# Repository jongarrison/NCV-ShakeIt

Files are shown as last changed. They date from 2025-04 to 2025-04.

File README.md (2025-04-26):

# NCV-ShakeIt
## (Non Contact Voltage Detecting Time Delayed Relay With Audio Feedback)

<div style="width: 100%; text-align: center;">
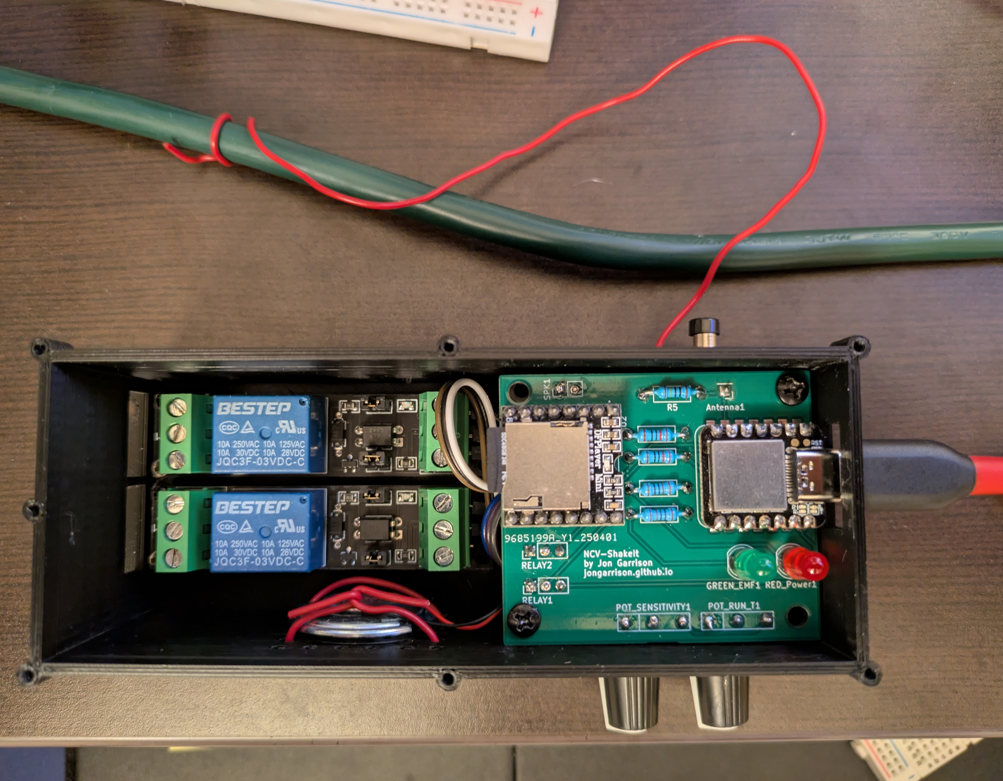
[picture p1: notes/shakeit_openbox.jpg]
    
</div>

This device is designed to turn on two relays (currently for a single two phase motor) after detecting that another AC device has shut off. The running of the other AC device is detected using a Non-contact Voltage (NCV) detector. When the device is about to trigger the relays, it plays some audio feedback (mp3 files) to let people know the motor is about to run.

Basic functions:
* Device has an antenna for detecting 60hz AC power in a nearby wire. If AC is detected for longer than a minimum threshold the system is ready to trigger when the AC next shuts off. The sensitivity of the AC detection is controlled by a potentiometer knob.
* The device waits for some interval while the main motor system spools down. During this spool down period audio is played to indicate what is happening.
* After the spool down period, two relays are turned on for an interval set by another potentiometer knob. 

# Technical Details

### Non-contact Voltage Detector circuit and algorithm
* Based on this very cool project: https://www.instructables.com/Contactless-AC-Detector/

### PCB Design
* Kicad files are provided in ./PCB_NCV-ShakeIt

<div style="width: 100%; text-align: center;">
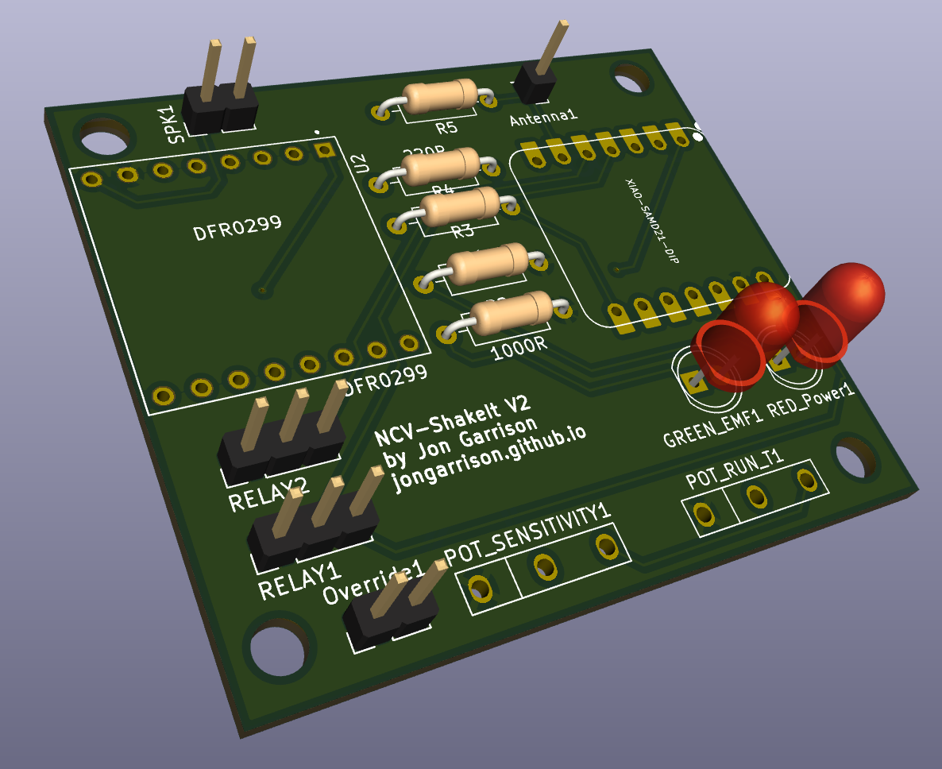
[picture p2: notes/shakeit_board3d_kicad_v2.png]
    
</div>

### Enclosure Design
* Done in Rhino3D Grasshopper. Files found in ./ShakeIt_enclosure

<div style="width: 100%; text-align: center;">
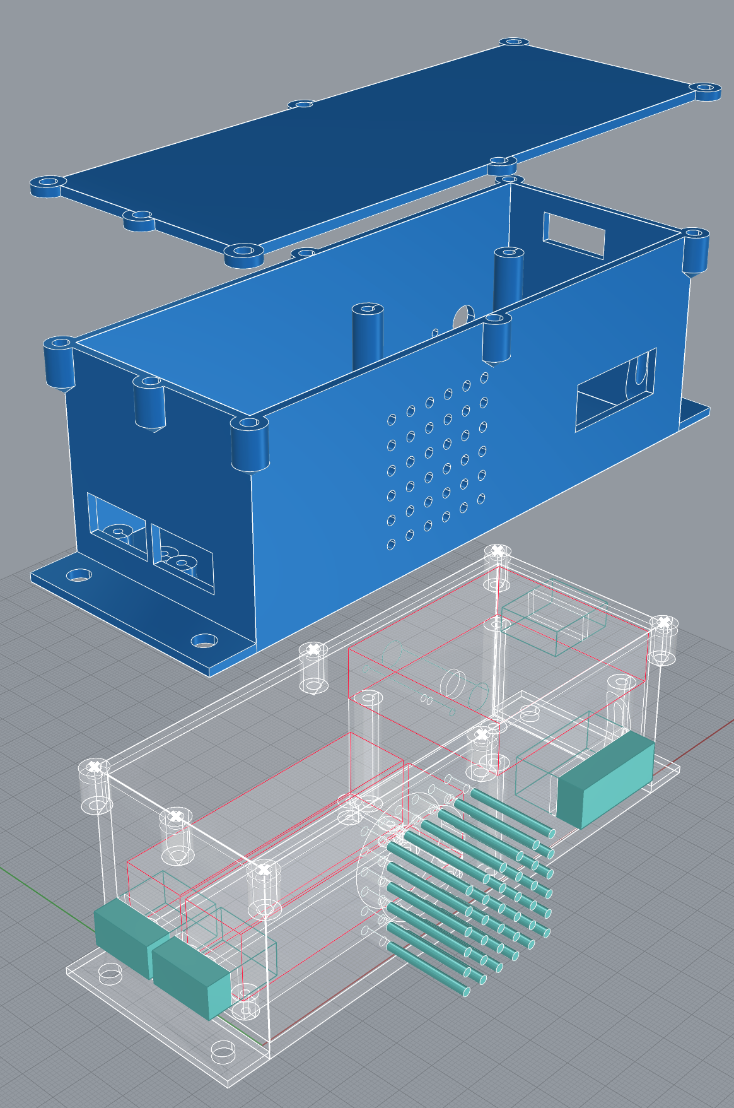
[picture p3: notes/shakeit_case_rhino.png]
    
</div>

### Microcontroller
* [Seeed Xiao SAMD21 board](https://wiki.seeedstudio.com/Seeeduino-XIAO/) - [Pinout](https://wiki.seeedstudio.com/Seeeduino-XIAO/#hardware-overview)

### MP3 Playback - DFPlayer
* [Usage Tips](https://reprage.com/posts/2018-05-08-dfplayer-mini-cheat-sheet/)

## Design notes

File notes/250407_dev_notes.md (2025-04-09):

4/7/25 Received the boards and assembled them. They work, BUT...

- Both speaker pins on the DF Mini Player should have been exposed via the header outputs
- An override switch should have been included
- Some sort of access to the SAMD21 reset is needed. Perhaps some terminals to pads for a switch? Perhaps have jumper wires from the topside reset contacts to the terminals
- Expose all of the pins of the SAMD21 with through hole connectors alongside the existing pin pads? This would allow easier repurposing of the boards.
- Replace the 1M resistor with a 1M trim pot?

Notes from initializing the 

        bool initDfPlayerWithRetry(int volume) {
            //Serial1.begin(9600); // Must be done in setup()

            while (!initDfPlayer(volume)) {
                Serial.println(F("Retrying to initialize DFPlayer ..."));
                delay(5000);
            }

            if (myDFPlayer.available()) {
                printDfPlayerDetail(myDFPlayer.readType(), myDFPlayer.read());
            }

            return true;

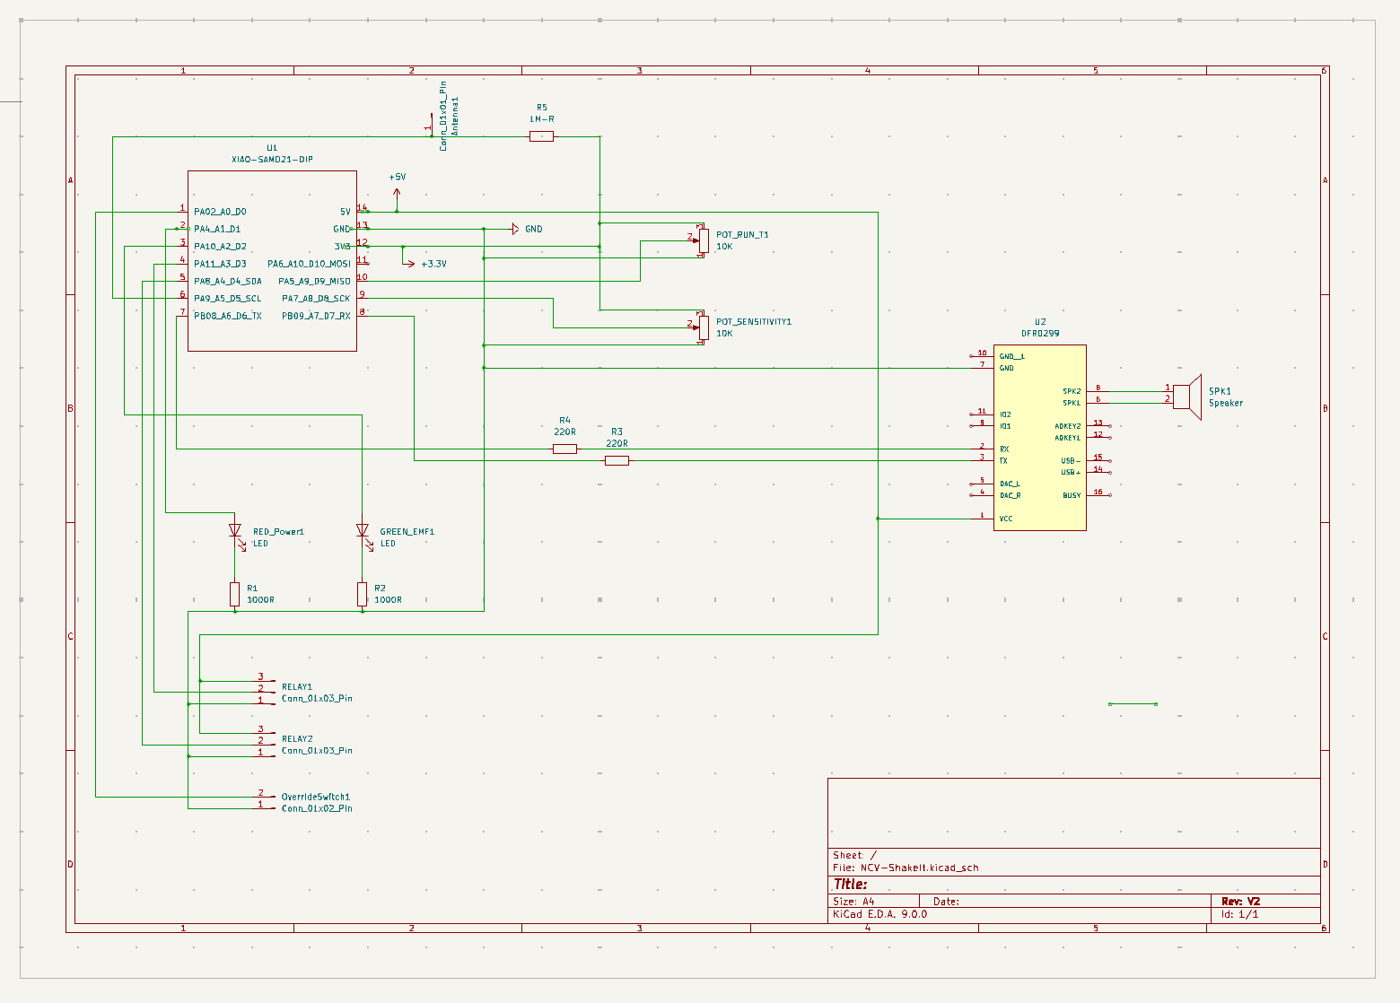
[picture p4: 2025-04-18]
notes/shakeit_schematic.png

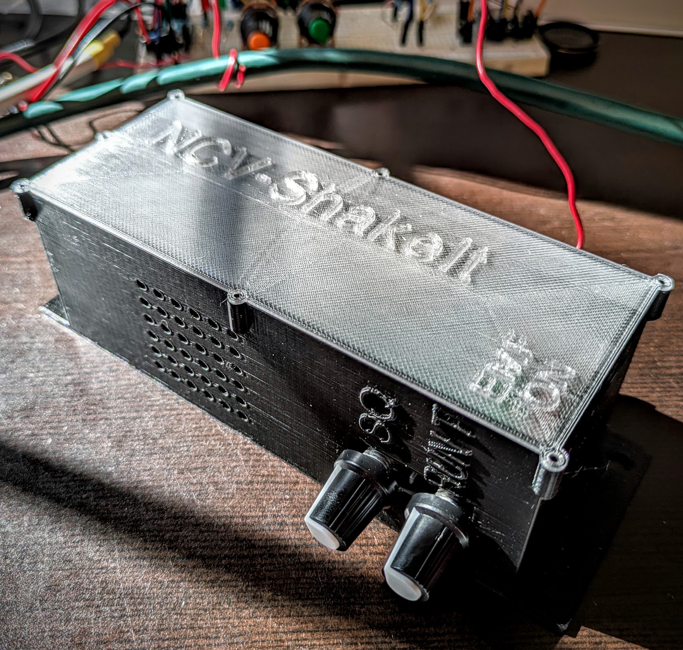
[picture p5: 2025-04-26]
notes/shakeit_complete.jpg

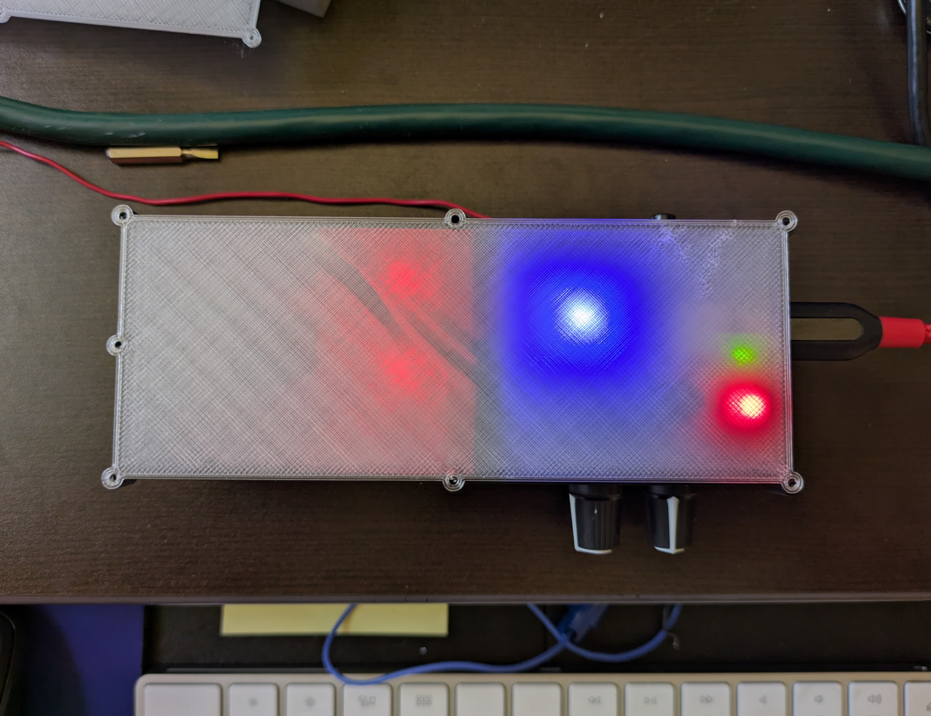
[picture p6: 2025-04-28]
notes/shakeit_lights.jpg

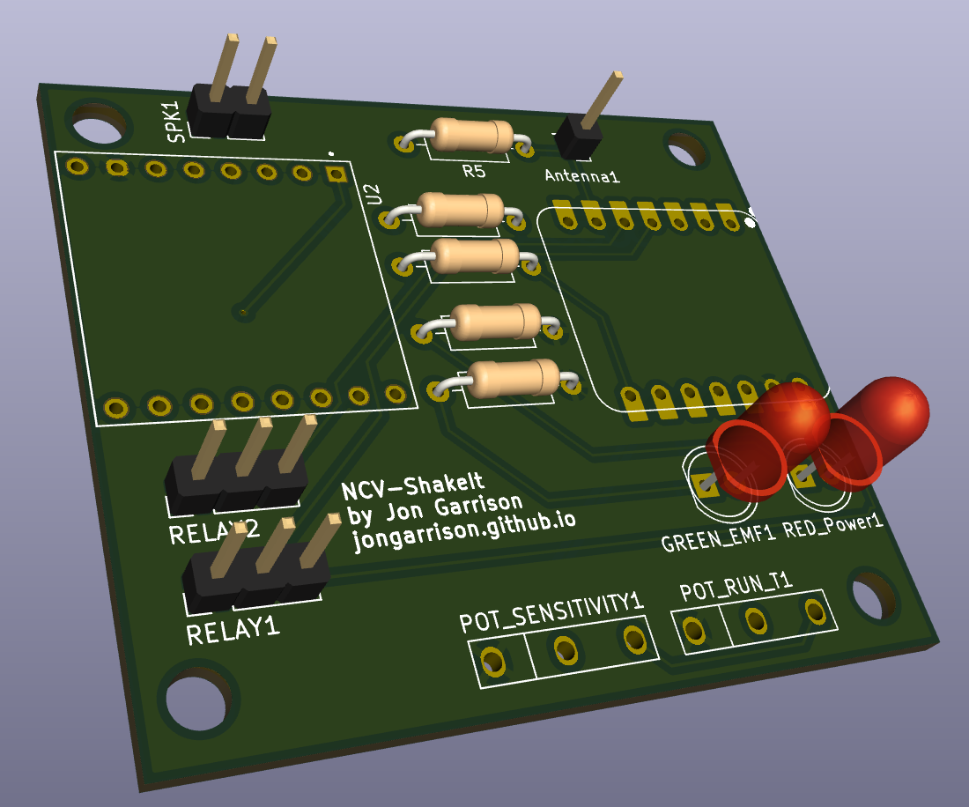
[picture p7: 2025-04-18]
notes/shakeit_board3d_kicad_v1.png

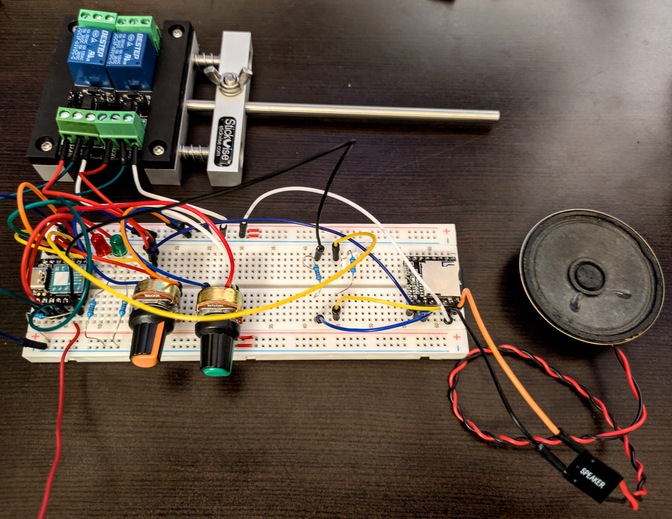
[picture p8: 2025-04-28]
notes/shakeit_prototype.jpg

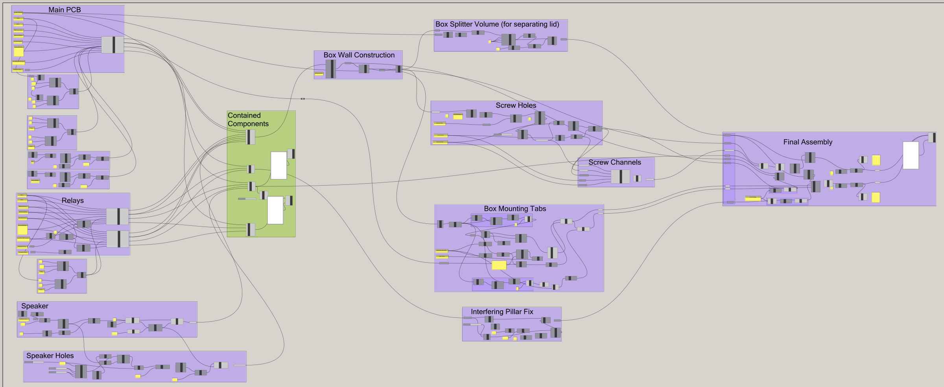
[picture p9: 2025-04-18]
notes/shakeit_grasshopper.png

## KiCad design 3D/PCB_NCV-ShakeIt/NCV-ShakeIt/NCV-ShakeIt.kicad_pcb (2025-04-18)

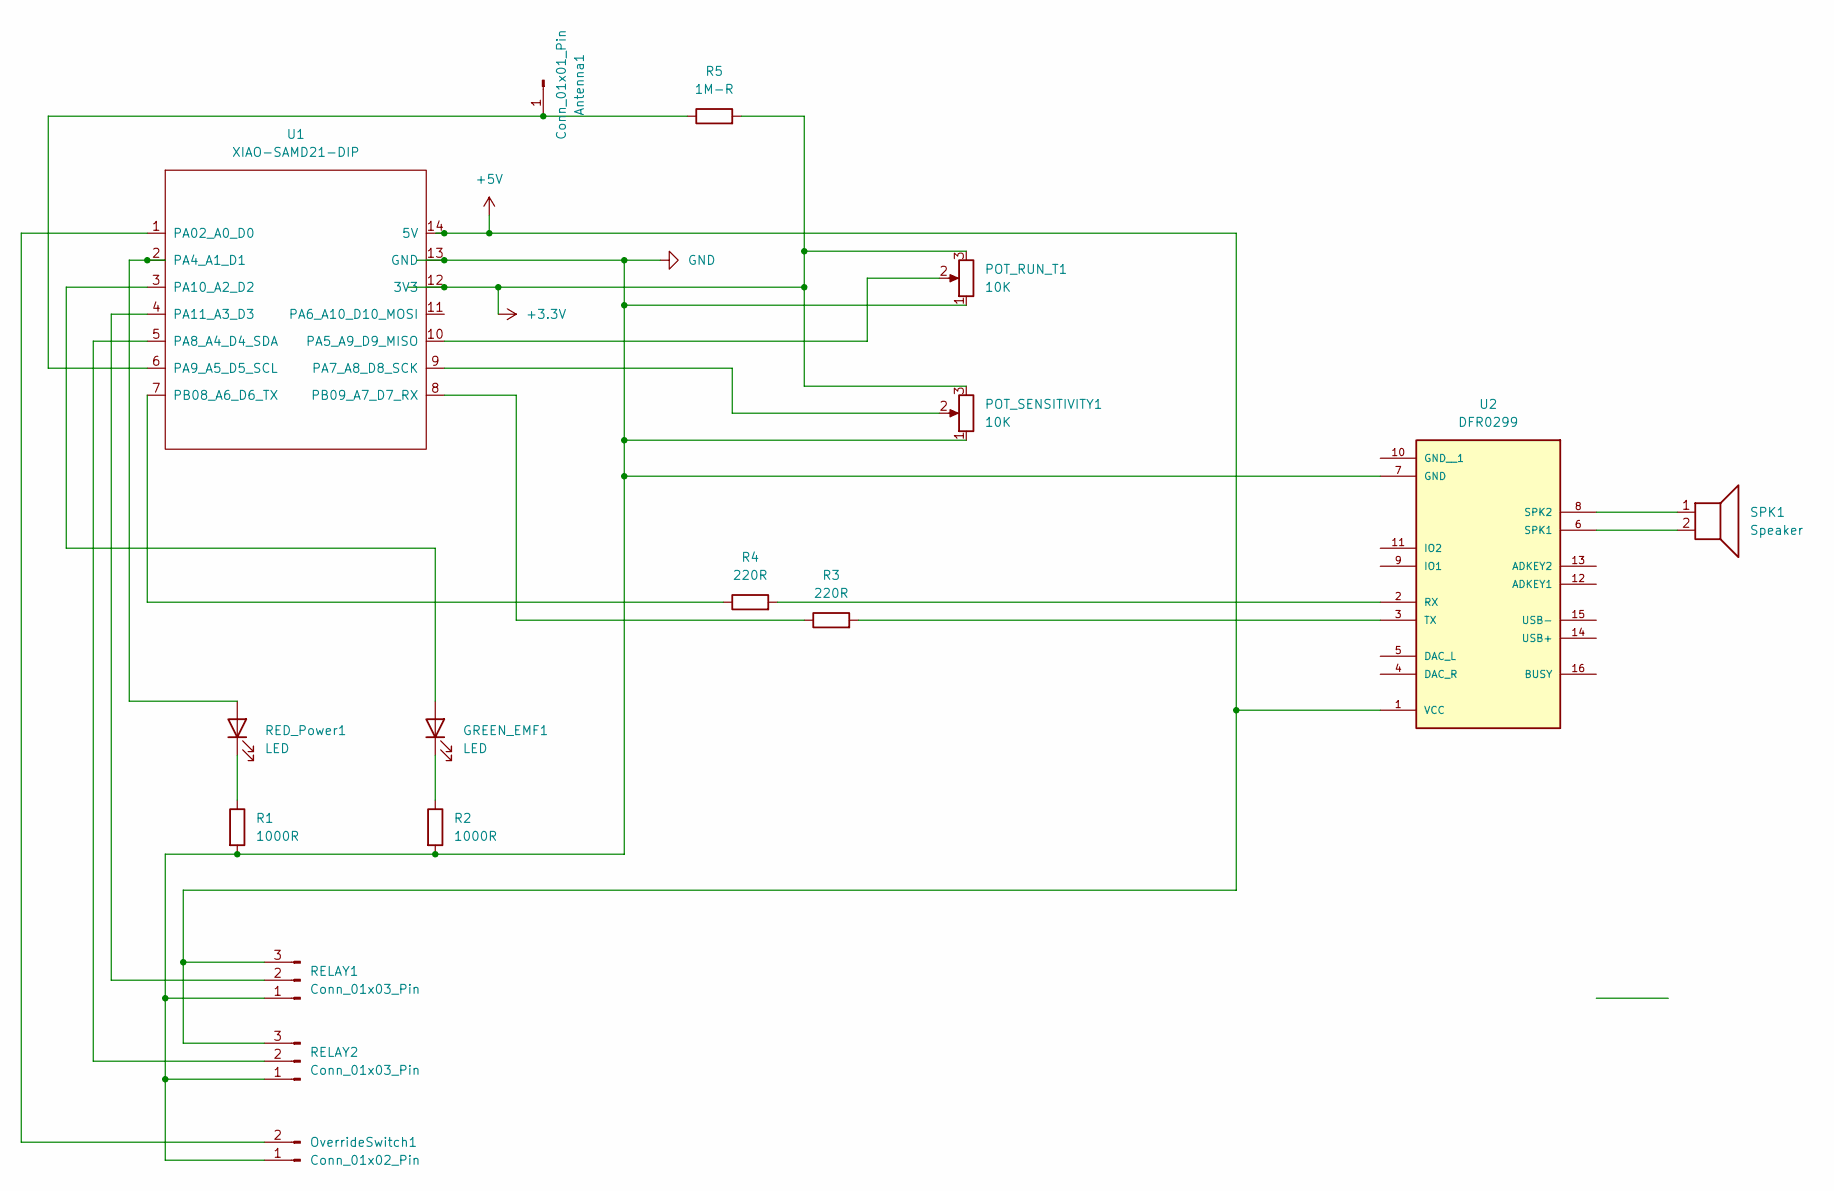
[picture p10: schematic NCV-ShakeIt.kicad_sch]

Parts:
Antenna1: Conn_01x01_Pin; PinHeader_1x01_P2.54mm_Vertical
GREEN_EMF1: LED; LED_D5.0mm
OverrideSwitch1: Conn_01x02_Pin; PinHeader_1x02_P2.54mm_Vertical
POT_RUN_T1: 10K; JG-3Pin-Pot-11mmOuterPins
POT_SENSITIVITY1: 10K; JG-3Pin-Pot-11mmOuterPins
R1, R2: 1000R; R_Axial_DIN0207_L6.3mm_D2.5mm_P10.16mm_Horizontal
R3, R4: 220R; R_Axial_DIN0207_L6.3mm_D2.5mm_P10.16mm_Horizontal
R5: 1M-R; R_Axial_DIN0207_L6.3mm_D2.5mm_P10.16mm_Horizontal
RED_Power1: LED; LED_D5.0mm
RELAY1, RELAY2: Conn_01x03_Pin; PinHeader_1x03_P2.54mm_Vertical
SPK1: Speaker; PinHeader_1x02_P2.54mm_Vertical
U1: XIAO-SAMD21-DIP
U2: DFR0299; MODULE_DFR0299

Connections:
+3.3V: POT_RUN_T1.3, POT_SENSITIVITY1.3, R5.2, U1.12 (3V3)
+5V: RELAY1.3, RELAY2.3, U1.14 (5V), U2.1 (VCC)
GND: OverrideSwitch1.1, POT_RUN_T1.1, POT_SENSITIVITY1.1, R1.2, R2.2, RELAY1.1, RELAY2.1, U1.13 (GND), U2.7 (GND); also elsewhere on the board
unnamed: Antenna1.1, R5.1, U1.6 (PA9_A5_D5_SCL)
unnamed: GREEN_EMF1.2 (A), U1.3 (PA10_A2_D2)
unnamed: GREEN_EMF1.1 (K), R2.1
unnamed 6: OverrideSwitch1.2, U1.1 (PA02_A0_D0); also elsewhere on the board
unnamed: RED_Power1.2 (A), U1.2 (PA4_A1_D1)
unnamed: R1.1, RED_Power1.1 (K)
unnamed: RELAY1.2, U1.4 (PA11_A3_D3)
unnamed: RELAY2.2, U1.5 (PA8_A4_D4_SDA)
unnamed: POT_RUN_T1.2, U1.10 (PA5_A9_D9_MISO)
unnamed: POT_SENSITIVITY1.2, U1.9 (PA7_A8_D8_SCK)
unnamed: R4.1, U1.7 (PB08_A6_D6_TX)
unnamed: R3.1, U1.8 (PB09_A7_D7_RX)
unnamed: R4.2, U2.2 (RX)
unnamed: SPK1.2, U2.6 (SPK1)
unnamed: SPK1.1, U2.8 (SPK2)
unnamed: R3.2, U2.3 (TX)

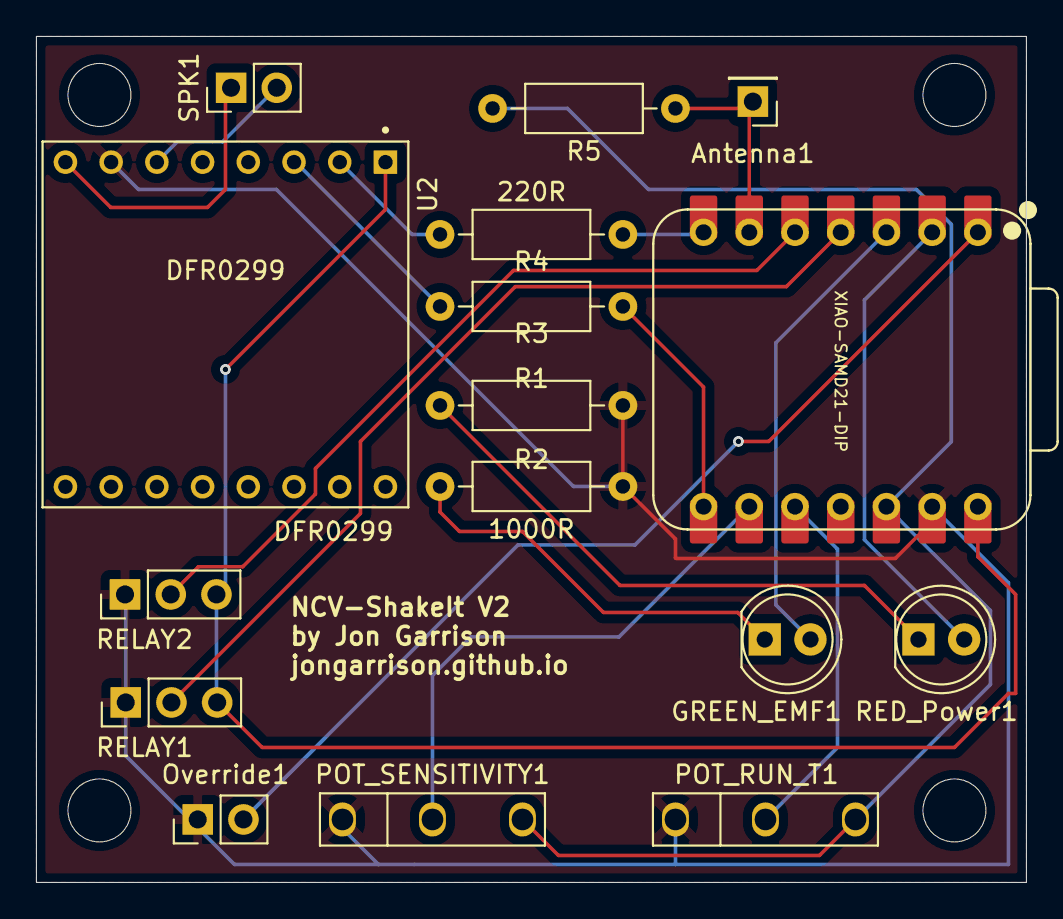
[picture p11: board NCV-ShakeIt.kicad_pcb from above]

Board: 2 copper layers, 55.0 x 47.0 mm, 16 parts (0 on the bottom side), 19 nets.

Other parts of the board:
Override1: Conn_01x02_Pin; PinHeader_1x02_P2.54mm_Vertical

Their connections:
GND: Override1.1; also elsewhere on the board
unnamed 6: Override1.2; also elsewhere on the board

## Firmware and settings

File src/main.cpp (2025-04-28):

#include <Arduino.h>
#include "constants.h"
#include "state.h"
#include "action.h"
#include <AceButton.h>
using namespace ace_button;

/**
 * This button handler lives outside of both action and state because it 
 * can initiate actions in both modules.
 */
void handleUserOverrideButton(AceButton* /*button*/, uint8_t eventType, uint8_t /*buttonState*/) {
    Serial.print("Override button event: ");
    Serial.println(eventType);

    if (eventType == AceButton::kEventClicked) {
        Serial.println("kEventClick - Activating relay sequence");
        state::transitionTo(state::ACTIVATING);
        action::displayUserEvent();
    } else if (eventType == AceButton::kEventDoubleClicked) {
        Serial.println("kEventDoubleClicked - Playing random track");
        action::userPlayRandomTrack();
    } else if (eventType == AceButton::kEventLongPressed) {
        Serial.println("kEventLongPressed - Setting volume based on reuse of Timing Knob");
        action::userSetVolume();
    }
}

void setup() {
    action::initHardware(handleUserOverrideButton);
    state::init();

    action::timer.setInterval(500, []() {
        state::update();
    });
}

void loop() {
    action::doLoop();
}

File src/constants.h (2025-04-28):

#ifndef CONSTANTS_H
#define CONSTANTS_H

// Pin definitions
#define PIN_TIMEKNOB A9
#define PIN_SQUELCHKNOB A8
#define PIN_LED_POWER_INDICATOR A1
#define PIN_LED_TRIGGER_INDICATOR A2
#define PIN_RELAY1 A3
#define PIN_RELAY2 A4
#define PIN_USER_OVERRIDE_BUTTON 0
#define PIN_EMF_ANTENNA A5

// MP3 Player settings
#define PIN_DFPLAY_MP3_RX D7
#define PIN_DFPLAY_MP3_TX D6
#define DFPLAY_MP3_VOLUME_DEFAULT 25
#define DFPLAY_MIN_TRACK 1
#define DFPLAY_MAX_TRACK 3

// Pot knob settings
#define POTKNOB_RUNT_MIN_MS 2000
#define POTKNOB_RUNT_MAX_MS 30000
#define POTKNOB_SQUELCH_MIN 1.0
#define POTKNOB_SQUELCH_MAX 30.0
#define POTKNOB_VOLUME_MIN 0.0
#define POTKNOB_VOLUME_MAX 30.0

// State machine timings
#define STATE_MINIMUM_EMF_DETECTION_TIME_MS (5 * 1000)
#define STATE_SPINDOWN_WAIT_TIME_MS (10 * 60 * 1000)
#define STATE_MUSIC_PLAY_TIME_MS (10 * 1000)

// EMF detection settings
#define NCV_EMF_SAMPLE_COUNT 200
#define NCV_POWER_HZ 60

#endif // CONSTANTS_H

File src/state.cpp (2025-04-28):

#include "Arduino.h"
#include "state.h"
#include "action.h"
#include "ncv.h"
#include "dfplay.h"

namespace state {
    // Current state of the system
    static State currentState = LISTENING;

    // Timestamp when EMF was first detected
    static unsigned long emfFirstDetectedTime = 0;

    // Makes sure that the relays get run even if multiple EMF detection cycles occur
    // Imagine the scenario of a solid triggering, but during the spindown wait a short EMF
    // detection occurs, this would clear the spindown wait instead of restarting it
    static bool isRelayRunNeeded = false;

    // Timer IDs for the different timers we'll use
    static int spindownTimerId = -1;
    static int musicTimerId = -1;
    static int relayStartTimerId = -1;
    static int relayStopTimerId = -1;
    static int spindownIndicatorTimerId = -1;

    // Helper function to cancel all timers
    void cancelAllTimers() {
        if (spindownTimerId != -1) {
            action::timer.deleteTimer(spindownTimerId);
            spindownTimerId = -1;
        }
        if (musicTimerId != -1) {
            action::timer.deleteTimer(musicTimerId);
            musicTimerId = -1;
        }
        if (relayStartTimerId != -1) {
            action::timer.deleteTimer(relayStartTimerId);
            relayStartTimerId = -1;
        }
        if (relayStopTimerId != -1) {
            action::timer.deleteTimer(relayStopTimerId);
            relayStopTimerId = -1;
        }
        if (spindownIndicatorTimerId != -1) {
            action::timer.deleteTimer(spindownIndicatorTimerId);
            spindownIndicatorTimerId = -1;
        }
    }

    void refreshDisplay() {
       // Entry actions for the new state
       switch (currentState) {
        case LISTENING:
            digitalWrite(PIN_LED_POWER_INDICATOR, HIGH);
            digitalWrite(PIN_LED_TRIGGER_INDICATOR, LOW);
            break;
            
        case EMF_DETECTED:
            digitalWrite(PIN_LED_POWER_INDICATOR, LOW);
            digitalWrite(PIN_LED_TRIGGER_INDICATOR, HIGH);
            break;
            
        case SPINDOWN_WAIT:
            digitalWrite(PIN_LED_POWER_INDICATOR, HIGH);
            digitalWrite(PIN_LED_TRIGGER_INDICATOR, LOW);
            break;
            
        case ACTIVATING:            
            digitalWrite(PIN_LED_POWER_INDICATOR, LOW);
            digitalWrite(PIN_LED_TRIGGER_INDICATOR, HIGH);
            break;
    }        
    }

    // State transition function
    void transitionTo(State newState) {
        // Don't transition if we're already in that state
        if (newState == currentState) return;
        
        Serial.print("State transition: ");
        Serial.print(getStateName(currentState));
        Serial.print(" -> ");
        Serial.println(getStateName(newState));
        
        // Exit actions for the current state
        switch (currentState) {
            case EMF_DETECTED:
                // Reset EMF detection time
                emfFirstDetectedTime = 0;
                break;
                
            case SPINDOWN_WAIT:
                cancelAllTimers();
                break;
                
            case ACTIVATING:
                cancelAllTimers();
                action::relaysOff();
                dfplay::stop();                
                break;
                
            default:
                break;
        }
        
        // Update the current state
        currentState = newState;
        
        // Entry actions for the new state
        // LED state will be updated after the switch statement
        switch (newState) {
            case LISTENING:
                //All the work for LISTENING is done in the update function
                break;
                
            case EMF_DETECTED:
                // Record when EMF was first detected
                if (emfFirstDetectedTime == 0) {
                    emfFirstDetectedTime = millis();
                }                
                break;
                
            case SPINDOWN_WAIT:
                // Start the spindown timer
                spindownTimerId = action::timer.setTimeout(STATE_SPINDOWN_WAIT_TIME_MS, []() {
                    onSpindownComplete();
                });

                spindownIndicatorTimerId = action::timer.setInterval(1000, []() {
                    // Blink the LED to indicate spindown wait
                    static bool greenLedState = LOW;
                    greenLedState = !greenLedState;
                    digitalWrite(PIN_LED_TRIGGER_INDICATOR, greenLedState);
                });
                break;
                
            case ACTIVATING:
                // Start playing music
                dfplay::setVolume(action::getVolumeStorage());
                dfplay::playRandomTrack();
                
                // Set timer to stop music after the specified time
                musicTimerId = action::timer.setTimeout(STATE_MUSIC_PLAY_TIME_MS, []() {
                    dfplay::stop();
                });
            
                // Set timer to activate relays after music stops
                relayStartTimerId = action::timer.setTimeout(STATE_MUSIC_PLAY_TIME_MS + 500, []() {
                    action::relaysOn();
                    
                    // After relay sequence completes, transition back to LISTENING
                    // This is handled by the activateRelaySequence function which will
                    // set a timer to turn off the relays and set isEmfScanningOn to true
                });

                relayStopTimerId = action::timer.setTimeout(STATE_MUSIC_PLAY_TIME_MS + 500 + action::getRelayOnDurationMs(), []() {
                    isRelayRunNeeded = false; // the relay run cycle completed
                    onActivationComplete();
                });                
                break;
        }
        refreshDisplay();
    }

    // Initialize the state machine
    void init() {
        currentState = LISTENING;
        emfFirstDetectedTime = 0;
        cancelAllTimers();
        
        // Set initial state
        transitionTo(LISTENING);
    }

    // Update the state machine based on current conditions
    void update() {
        // Check for EMF detection
        bool wasEmfDetected = action::isEmfDetected();
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

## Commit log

2025-04-09 Including more kicad files and improving the potentiometer adjustment code
    [DustBin_PCB-B_Cu.gbr, DustBin_PCB-B_Mask.gbr, DustBin_PCB-B_Paste.gbr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]
2025-04-17 Checking in mostly grasshopper enclosure generation stuff and some clean up to the main code
2025-04-18 Adding to docs, fixing code, renaming things to be more clear
    [NCV-ShakeIt-B_Cu.gbr, NCV-ShakeIt-B_Mask.gbr, NCV-ShakeIt-B_Paste.gbr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]
2025-04-20 Added AceButton to allow various button behaviors. Added a long press volume set feature. Persisted volume setting with FlashStorage library, very cool
2025-04-24 organizing the 3D elements
    [NCV-ShakeIt-B_Cu.gbr, NCV-ShakeIt-B_Mask.gbr, NCV-ShakeIt-B_Paste.gbr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]
